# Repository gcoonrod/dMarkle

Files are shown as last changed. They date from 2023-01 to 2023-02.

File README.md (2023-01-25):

<!--
 dMarkle (c) by Greg Coonrod
 
 dMarkle is licensed under a
 Creative Commons Attribution-ShareAlike 4.0 International License.
 
 You should have received a copy of the license along with this
 work. If not, see <http://creativecommons.org/licenses/by-sa/4.0/>.
-->

# dMarkle

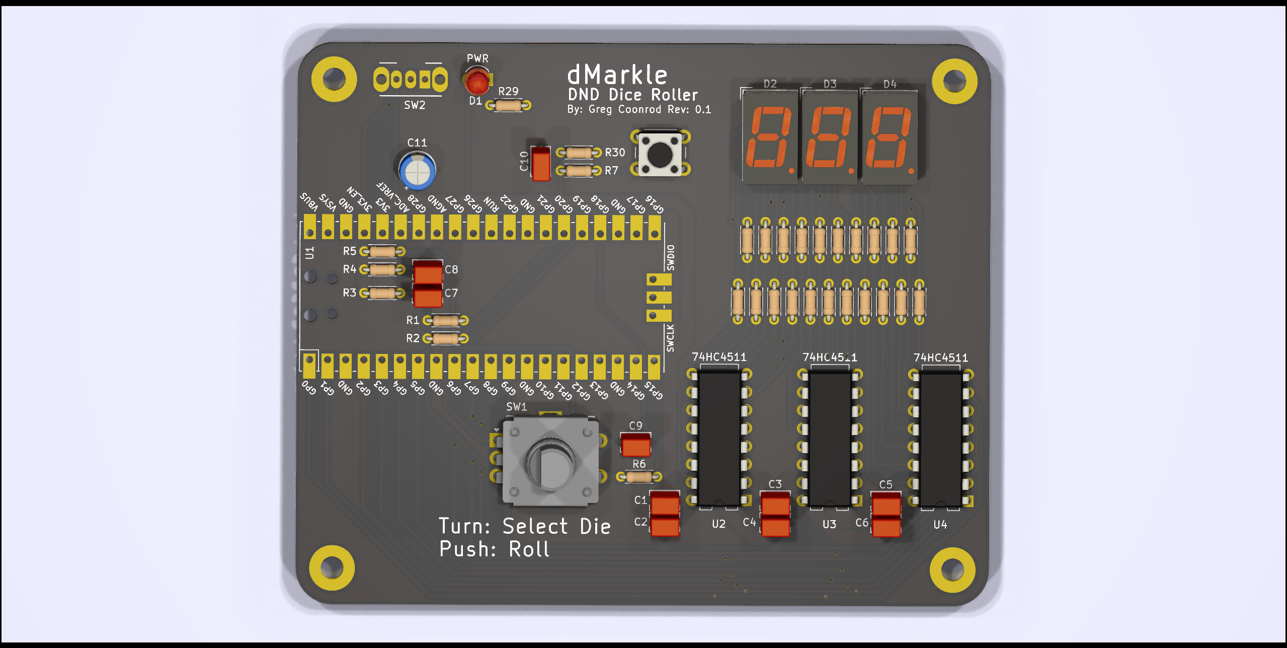
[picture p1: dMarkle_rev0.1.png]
3D View


A Raspberry Pi Pico based dice rolling toy.

## Usage

The dMarkle is programmed to roll one of any d4, d6, d8, d10, d12, d20, or d100 dice. The rotary encoder can be turned to select the die and then pushed to roll.

## Schematic and PCB

- Current [Schematic](./dMarkle-schematic-rev0.1.pdf)
- Current [PCB](./dMarkle-board-rev0.1.pdf)
  - The Pi Pico will be mounted on pin sockets. Hence the components that would otherwise be in an exclusion zone.

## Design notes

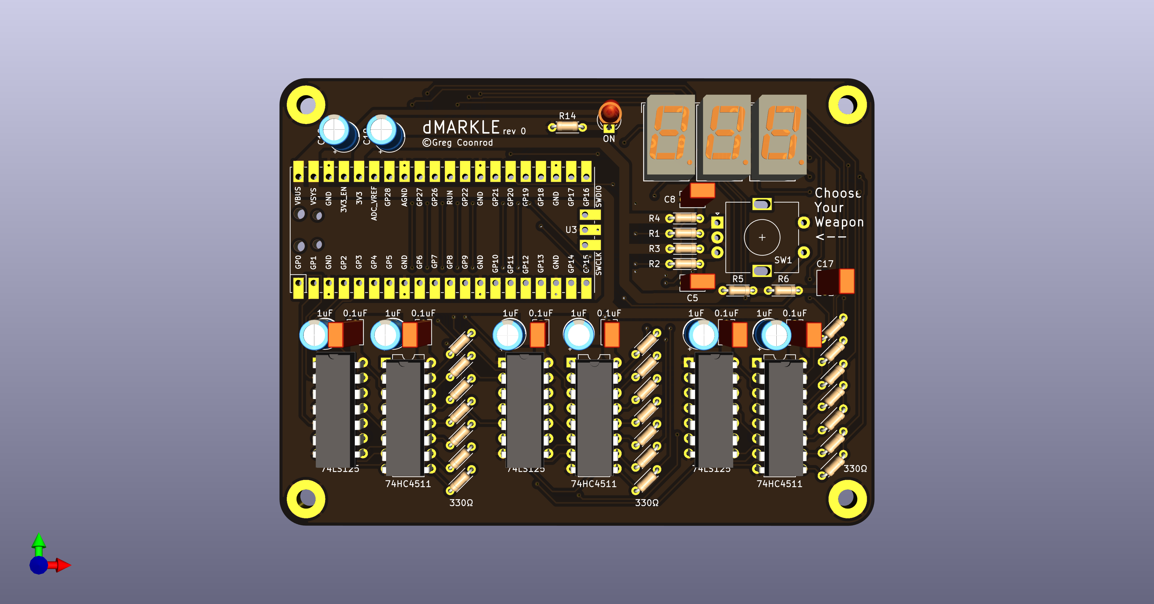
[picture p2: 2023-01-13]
dMarkle_rev0.png

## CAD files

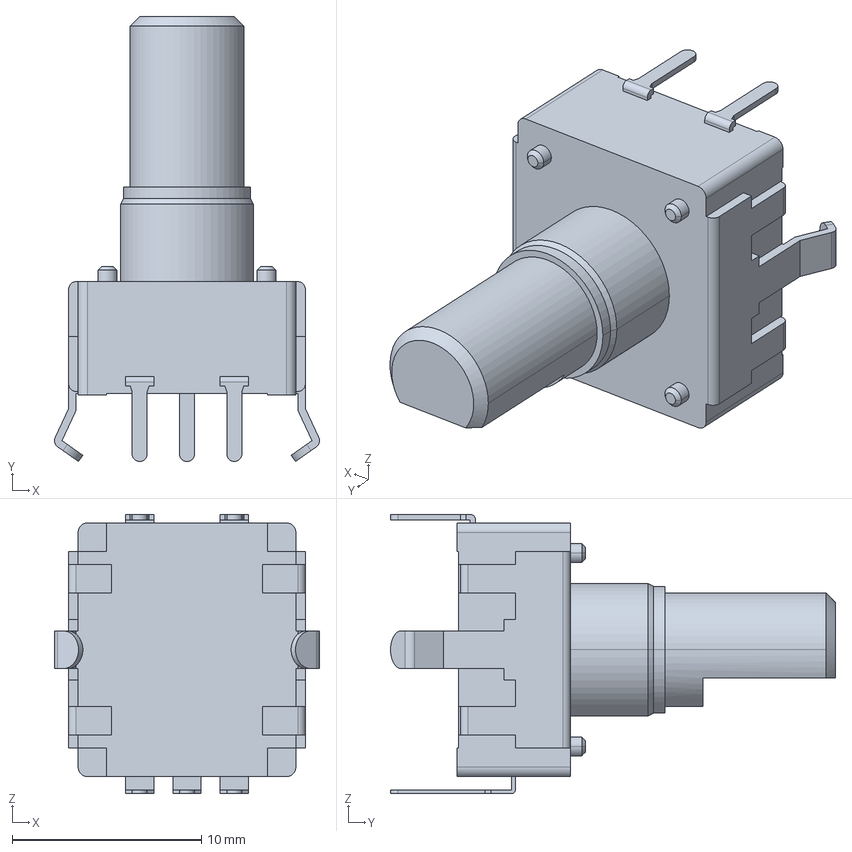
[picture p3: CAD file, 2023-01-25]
models/pec12r-4x20f-sxxxx.stp
14.0 x 23.5 x 14.7 mm

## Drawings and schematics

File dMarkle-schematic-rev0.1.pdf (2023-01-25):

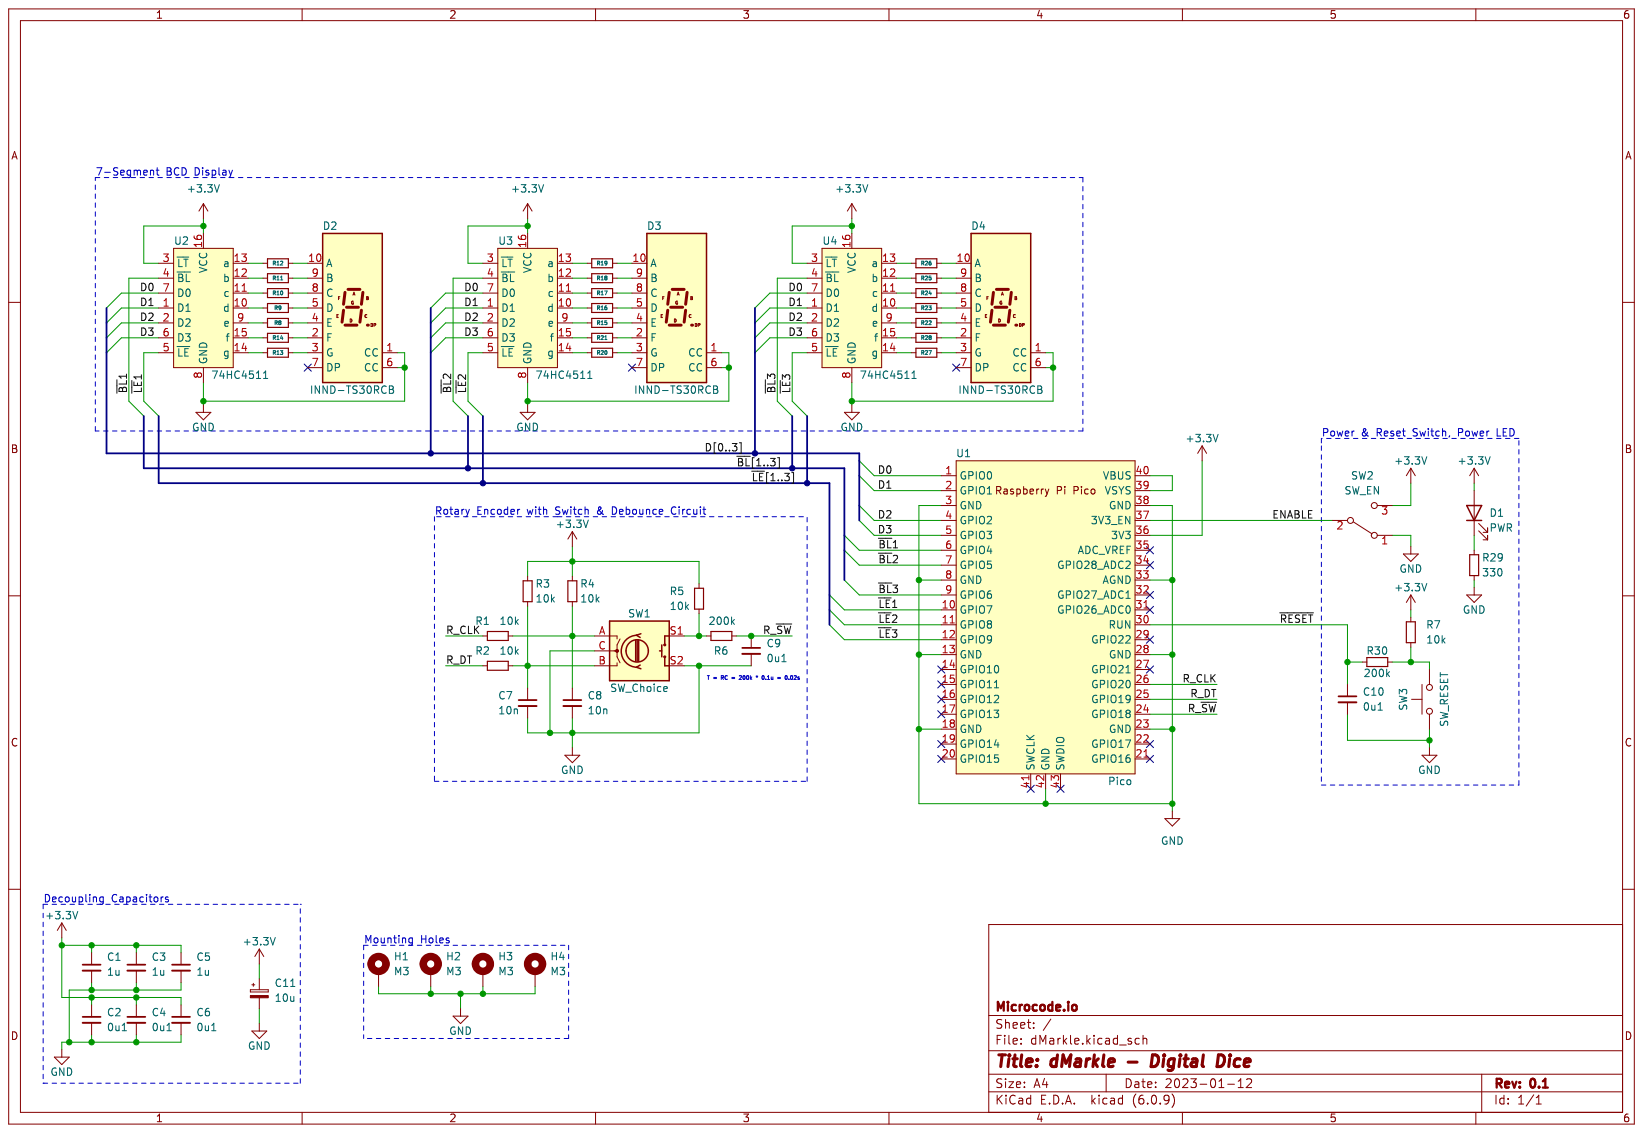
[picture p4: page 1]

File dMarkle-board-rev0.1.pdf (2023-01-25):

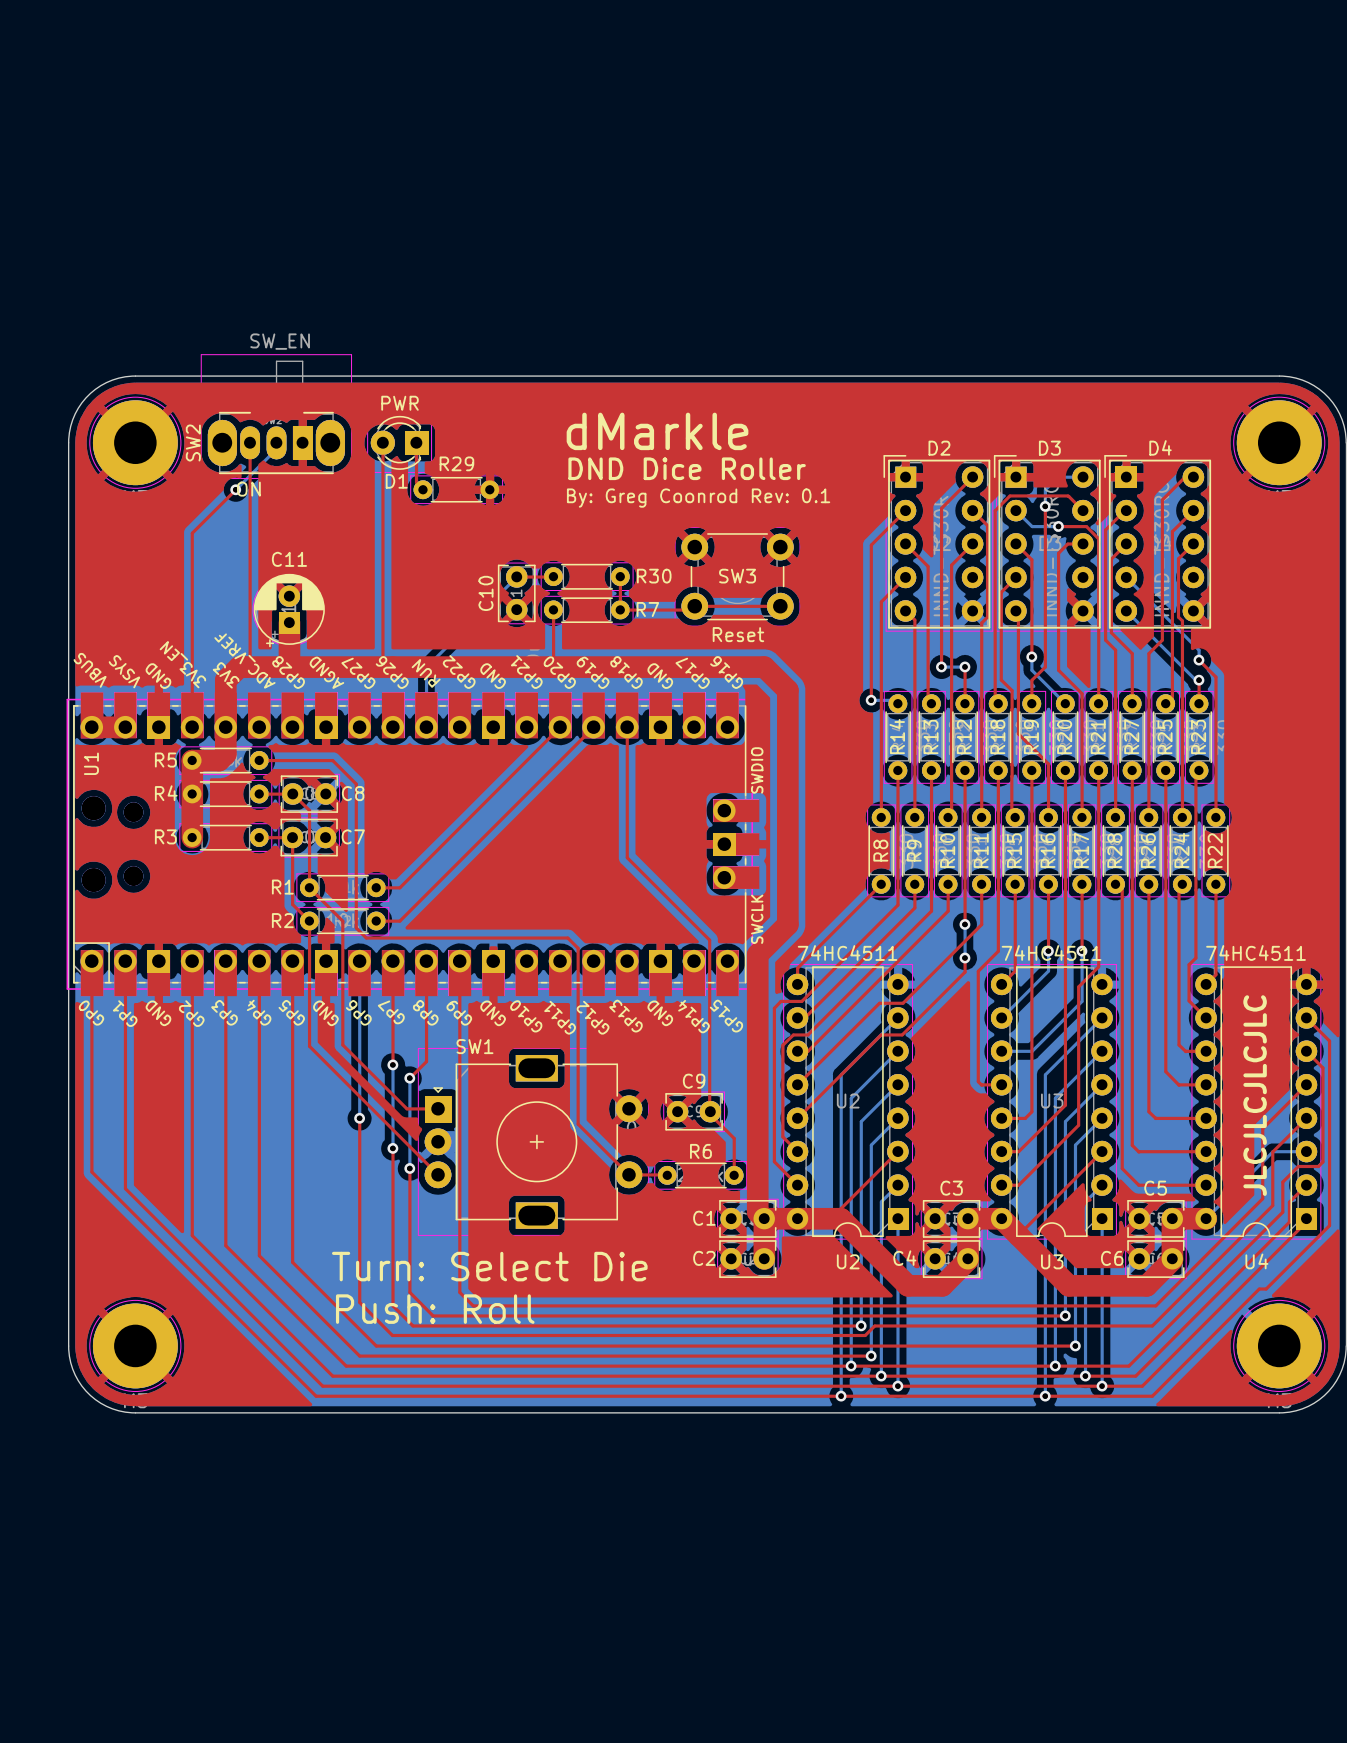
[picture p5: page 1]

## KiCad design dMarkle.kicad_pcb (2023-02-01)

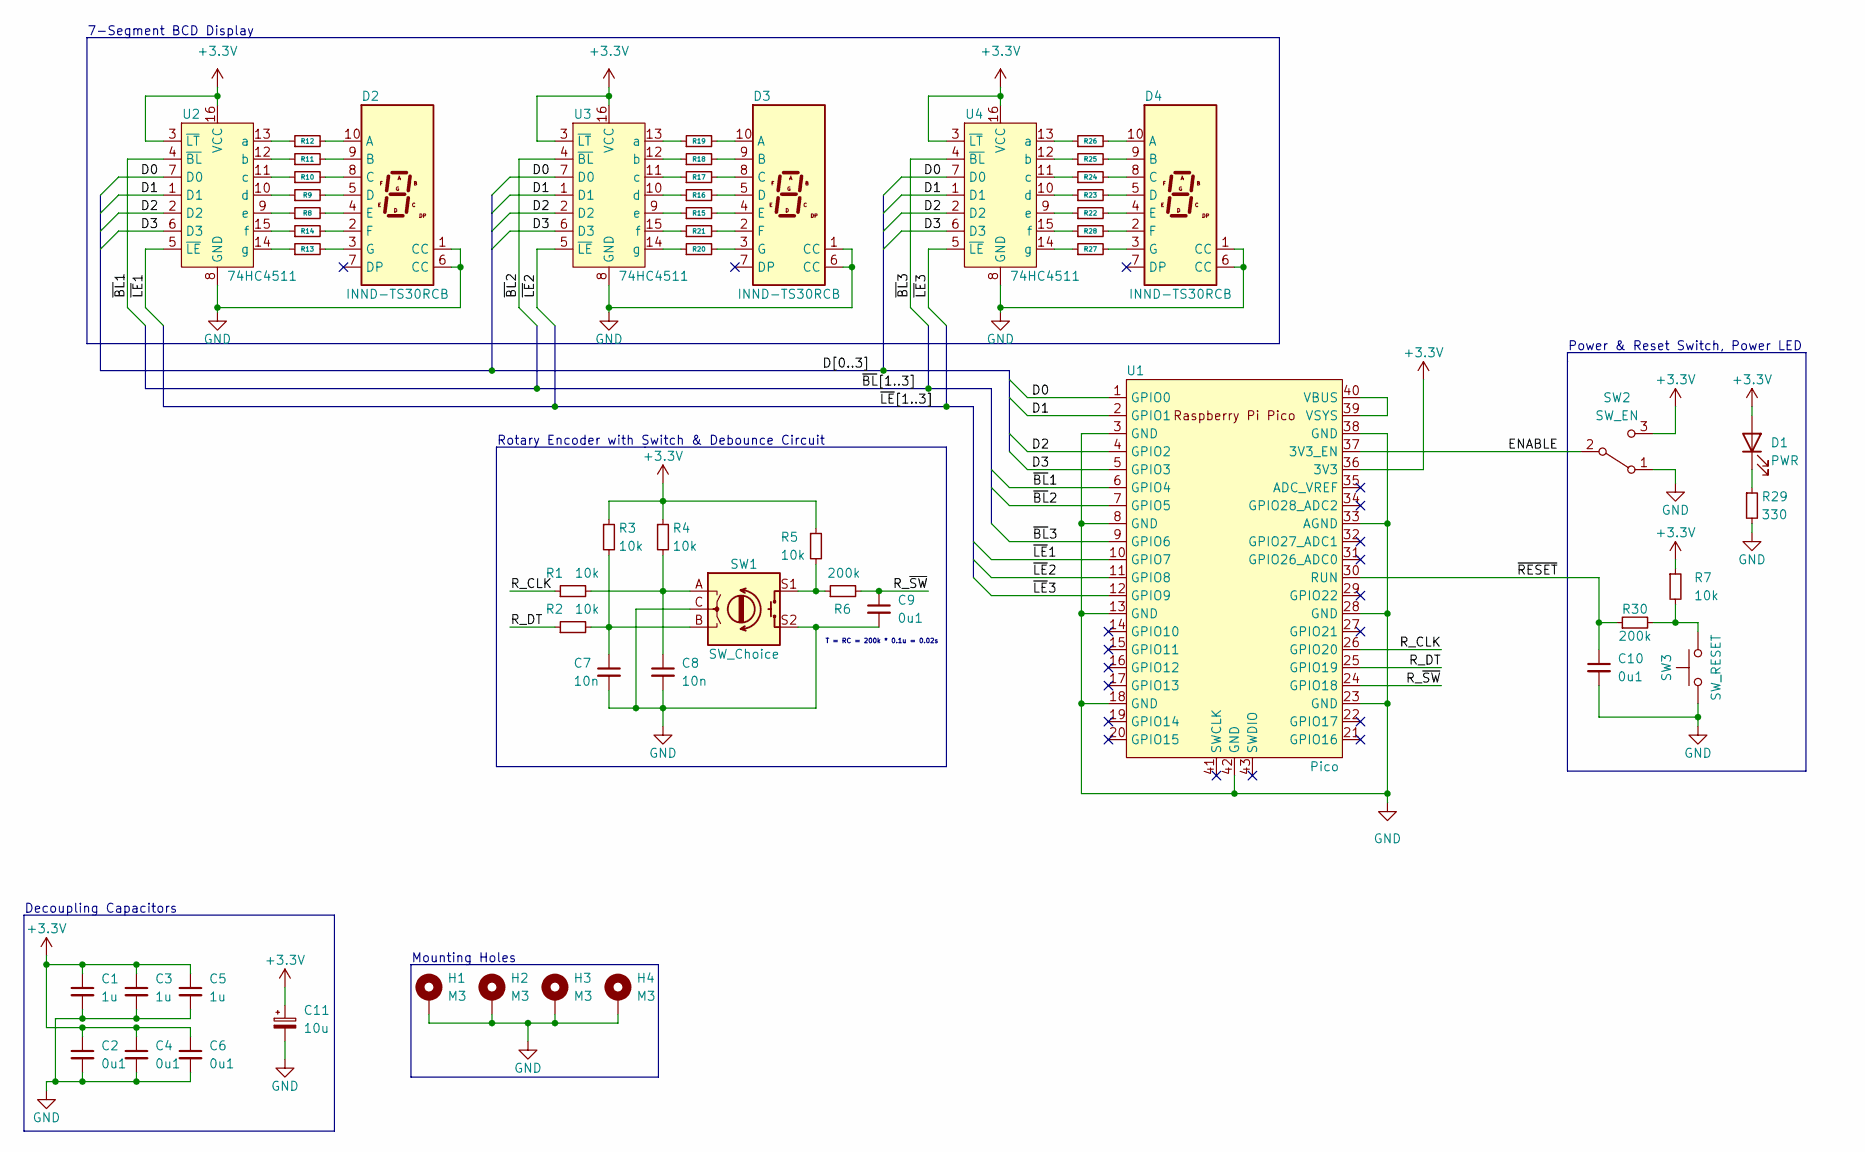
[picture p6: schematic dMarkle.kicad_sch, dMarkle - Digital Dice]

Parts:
C1, C3, C5: 1u; C_Rect_L4.0mm_W2.5mm_P2.50mm; Manufacturer Part Number FG18X5R1H105KRT06
C2, C4, C6, C9, C10: 0u1; C_Rect_L4.0mm_W2.5mm_P2.50mm; Manufacturer Part Number K104K15X7RF5TL2
C7, C8: 10n; C_Rect_L4.0mm_W2.5mm_P2.50mm; Manufacturer Part Number K103K15X7RF5TL2
C11: 10u; CP_Radial_D5.0mm_P2.00mm; Manufacturer Part Number 50YXM10MEFRTA5X11
D1: PWR; LED_D3.0mm; Manufacturer Part Number 151031SS04000
D2, D3, D4: INND-TS30RCB; HDSP-A151; Manufacturer Part Number INND-TS30RCB
H1, H2, H3, H4: M3; MountingHole_3.2mm_M3_Pad
R1, R2, R3, R4, R5, R7: 10k; R_Axial_DIN0204_L3.6mm_D1.6mm_P5.08mm_Horizontal; Manufacturer Part Number MBA02040C1002FRP00
R6, R30: 200k; R_Axial_DIN0204_L3.6mm_D1.6mm_P5.08mm_Horizontal; Manufacturer Part Number MBA02040C2003FCT00
R8, R9, R10, R11, R12, R13, R14, R15, R16, R17, R18, R19, R20, R21, R22, R23, R24, R25, R26, R27, R28, R29: 330; R_Axial_DIN0204_L3.6mm_D1.6mm_P5.08mm_Horizontal; Manufacturer Part Number MBA02040C3300FCT00
SW1: SW_Choice; RotaryEncoder_Alps_EC11E-Switch_Vertical_H20mm; Manufacturer Part Number PEC12R-4220F-S0024
SW2: SW_EN; SW_CuK_OS102011MA1QN1_SPDT_Angled; Manufacturer Part Number OS102011MA1QN1
SW3: SW_RESET; SW_PUSH_6mm; Manufacturer Part Number TL1105F160Q
U1: Pico; RPi_Pico_SMD_TH; Manufacturer Part Number SC0917
U2, U3, U4: 74HC4511; DIP-16_W7.62mm; Manufacturer Part Number CD74HC4511E

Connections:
+3.3V: C1.1, C2.1, C3.1, C4.1, C5.1, C6.1, C11.1, D1.2 (A), R3.1, R4.1, R5.1, R7.1, SW2.3 (C), U1.36 (3V3), U2.3 (~LT), U2.16 (VCC), U3.3 (~LT), U3.16 (VCC), U4.3 (~LT), U4.16 (VCC)
/D0: U1.1 (GPIO0), U2.7 (D0), U3.7 (D0), U4.7 (D0)
/D1: U1.2 (GPIO1), U2.1 (D1), U3.1 (D1), U4.1 (D1)
/D2: U1.4 (GPIO2), U2.2 (D2), U3.2 (D2), U4.2 (D2)
/D3: U1.5 (GPIO3), U2.6 (D3), U3.6 (D3), U4.6 (D3)
/ENABLE: SW2.2 (B), U1.37 (3V3_EN)
/R_CLK: R1.1, U1.26 (GPIO20)
/R_DT: R2.1, U1.25 (GPIO19)
/R_~SW: C9.1, R6.2, U1.24 (GPIO18)
/~BL1: U1.6 (GPIO4), U2.4 (~BL)
/~BL2: U1.7 (GPIO5), U3.4 (~BL)
/~BL3: U1.9 (GPIO6), U4.4 (~BL)
/~LE1: U1.10 (GPIO7), U2.5 (~LE)
/~LE2: U1.11 (GPIO8), U3.5 (~LE)
/~LE3: U1.12 (GPIO9), U4.5 (~LE)
/~RESET: C10.1, R30.1, U1.30 (RUN)
GND: C1.2, C2.2, C3.2, C4.2, C5.2, C6.2, C7.2, C8.2, C9.2, C10.2, C11.2, D2.1 (CC), D2.6 (CC), D3.1 (CC), D3.6 (CC), D4.1 (CC), D4.6 (CC), H1.1, H2.1, H3.1, H4.1, R29.2, SW1.C, SW1.S2, SW2.1 (A), SW3.1, U1.3 (GND), U1.8 (GND), U1.13 (GND), U1.18 (GND), U1.23 (GND), U1.28 (GND), U1.33 (AGND), U1.38 (GND), U1.42 (GND), U2.8 (GND), U3.8 (GND), U4.8 (GND)
unnamed: C7.1, R2.2, R3.2, SW1.B
unnamed: C8.1, R1.2, R4.2, SW1.A
unnamed: D1.1 (K), R29.1
unnamed: D2.2 (F), R14.2
unnamed: D2.3 (G), R13.2
unnamed: D2.4 (E), R8.2
unnamed: D2.5 (D), R9.2
unnamed: D2.8 (C), R10.2
unnamed: D2.9 (B), R11.2
unnamed: D2.10 (A), R12.2
unnamed: D3.2 (F), R21.2
unnamed: D3.3 (G), R20.2
unnamed: D3.4 (E), R15.2
unnamed: D3.5 (D), R16.2
unnamed: D3.8 (C), R17.2
unnamed: D3.9 (B), R18.2
unnamed: D3.10 (A), R19.2
unnamed: D4.2 (F), R28.2
unnamed: D4.3 (G), R27.2
unnamed: D4.4 (E), R22.2
unnamed: D4.5 (D), R23.2
unnamed: D4.8 (C), R24.2
unnamed: D4.9 (B), R25.2
unnamed: D4.10 (A), R26.2
unnamed: R5.2, R6.1, SW1.S1
unnamed: R8.1, U2.9 (e)
unnamed: R9.1, U2.10 (d)
unnamed: R10.1, U2.11 (c)
unnamed: R11.1, U2.12 (b)
unnamed: R12.1, U2.13 (a)
unnamed: R13.1, U2.14 (g)
unnamed: R14.1, U2.15 (f)
unnamed: R15.1, U3.9 (e)
unnamed: R16.1, U3.10 (d)
unnamed: R17.1, U3.11 (c)
unnamed: R18.1, U3.12 (b)
unnamed: R19.1, U3.13 (a)
unnamed: R20.1, U3.14 (g)
unnamed: R21.1, U3.15 (f)
unnamed: R22.1, U4.9 (e)
unnamed: R23.1, U4.10 (d)
unnamed: R24.1, U4.11 (c)
unnamed: R25.1, U4.12 (b)
unnamed: R26.1, U4.13 (a)
unnamed: R27.1, U4.14 (g)
unnamed: R28.1, U4.15 (f)
unnamed: R7.2, R30.2, SW3.2
unnamed: U1.39 (VSYS), U1.40 (VBUS)

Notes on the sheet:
Decoupling Capacitors
Rotary Encoder with Switch & Debounce Circuit
7-Segment BCD Display
T = RC = 200k * 0.1u = 0.02s
Mounting Holes
Power & Reset Switch, Power LED

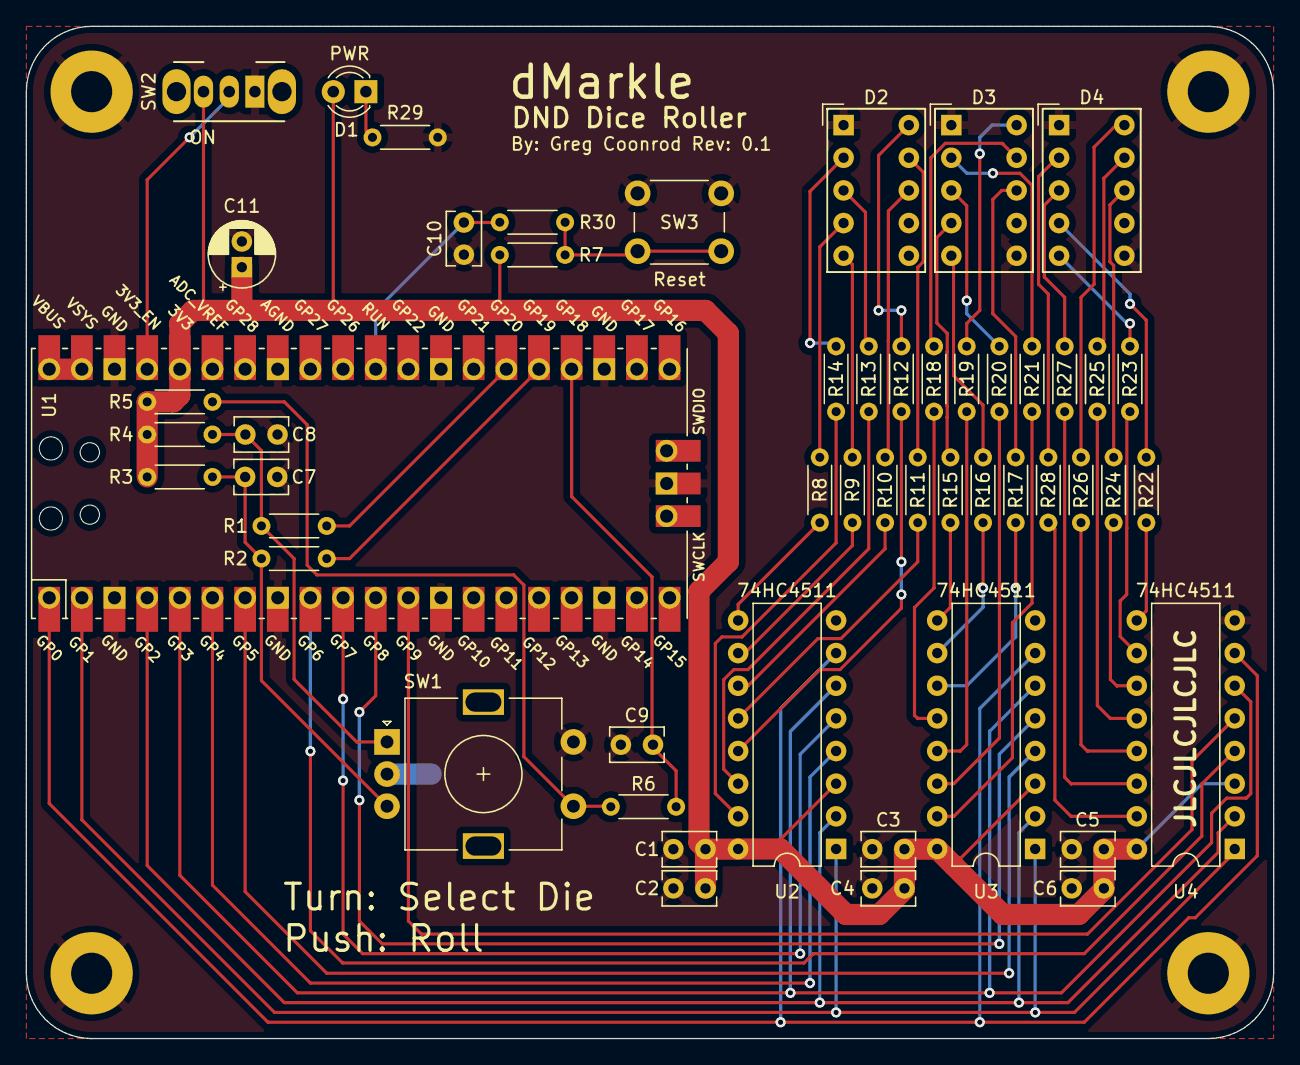
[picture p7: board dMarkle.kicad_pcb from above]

Board: 2 copper layers, 97.0 x 78.7 mm, 56 parts (0 on the bottom side), 65 nets.

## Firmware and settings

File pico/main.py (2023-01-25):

# dMarkle (c) by Greg Coonrod
#
# dMarkle is licensed under a
# Creative Commons Attribution-ShareAlike 4.0 International License.
#
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
from machine import Pin
import time
import random

NUMBERS = {
    0: dict(d3=0, d2=0, d1=0, d0=0, LE=0, BL=1, LT=1),
    1: dict(d3=0, d2=0, d1=0, d0=1, LE=0, BL=1, LT=1),
    2: dict(d3=0, d2=0, d1=1, d0=0, LE=0, BL=1, LT=1),
    3: dict(d3=0, d2=0, d1=1, d0=1, LE=0, BL=1, LT=1),
    4: dict(d3=0, d2=1, d1=0, d0=0, LE=0, BL=1, LT=1),
    5: dict(d3=0, d2=1, d1=0, d0=1, LE=0, BL=1, LT=1),
    6: dict(d3=0, d2=1, d1=1, d0=0, LE=0, BL=1, LT=1),
    7: dict(d3=0, d2=1, d1=1, d0=1, LE=0, BL=1, LT=1),
    8: dict(d3=1, d2=0, d1=0, d0=0, LE=0, BL=1, LT=1),
    9: dict(d3=1, d2=0, d1=0, d0=1, LE=0, BL=1, LT=1),
}

DICE = {
    'd4': dict(value=4, bits=3),
    'd6': dict(value=6, bits=3),
    'd8': dict(value=8, bits=4),
    'd10': dict(value=10, bits=4),
    'd12': dict(value=12, bits=4),
    'd20': dict(value=20, bits=5),
    'd100': dict(value=100, bits=7)
}

DICE_LIST = ['d4', 'd6', 'd8', 'd10', 'd12', 'd20', 'd100']


class Direction:
    LEFT = 0
    RIGHT = 1


class Digit:

    def __init__(self, pins):
        self.d3 = Pin(pins['d3'], Pin.OUT, value=0)
        self.d2 = Pin(pins['d2'], Pin.OUT, value=0)
        self.d1 = Pin(pins['d1'], Pin.OUT, value=0)
        self.d0 = Pin(pins['d0'], Pin.OUT, value=0)
        self.blank = Pin(pins['BL'], Pin.OUT, value=0)
        self.latch = Pin(pins['LE'], Pin.OUT, value=1)

    def set_value(self, value, blank=False):
        if blank:
            self.blank.off()
        else:
            self.blank.on()
            lookup = NUMBERS[value]
            self.d0.value(lookup['d0'])
            self.d1.value(lookup['d1'])
            self.d2.value(lookup['d2'])
            self.d3.value(lookup['d3'])
            time.sleep_us(50)
            self.latch.off()
            time.sleep_us(50)
            self.latch.on()
            time.sleep_us(50)

    def set_blank(self, value=True):
        if value:
            self.blank.off()
        else:
            self.blank.on()


class Display:

    def __init__(self):
        self.ones_digit = Digit(dict(d3=3, d2=2, d1=1, d0=0, LE=9, BL=6))
        self.tens_digit = Digit(dict(d3=3, d2=2, d1=1, d0=0, LE=8, BL=5))
        self.hundreds_digit = Digit(dict(d3=3, d2=2, d1=1, d0=0, LE=7, BL=4))

    def display_number(self, value):
        if value > 999 or value < 0:
            self.show_error()
        else:
            digits = list(str(value))
            digits.reverse()
            num_digits = len(digits)
            if num_digits > 0:
                self.ones_digit.set_value(int(digits[0]))
            else:
                self.ones_digit.set_blank()

            if num_digits > 1:
                self.tens_digit.set_value(int(digits[1]))
            else:
                self.tens_digit.set_blank()

            if num_digits > 2:
                self.hundreds_digit.set_value(int(digits[2]))
            else:
                self.hundreds_digit.set_blank()

    def show_error(self):
        print('Oops')


class RotaryEncoder:

    def __init__(self, clk_pin, dt_pin, btn_pin):
        self.clk = Pin(clk_pin, Pin.IN)
        self.dt = Pin(dt_pin, Pin.IN)

        # Active Low Button
        self.btn = Pin(btn_pin, Pin.IN)

        self.press_handler = None
        self.turn_handler = None

        self.clk.irq(self.__clk_irq_handler, Pin.IRQ_FALLING)
        self.btn.irq(self.__btn_irq_handler, Pin.IRQ_FALLING)

    def register_press_handler(self, handler_func):
        self.press_handler = handler_func

    def register_turn_handler(self, handler_func):
        self.turn_handler = handler_func

    def __clk_irq_handler(self, pin):
        dt_value = self.dt.value()
        #print('IRQ: dt={}'.format(dt_value))
        if dt_value == 0:
            if self.turn_handler != None:
                self.turn_handler(Direction.LEFT)
        else:
            if self.turn_handler != None:
                self.turn_handler(Direction.RIGHT)

    def __btn_irq_handler(self, pin):
        if self.press_handler != None:
            self.press_handler()


class Program:

    def __init__(self):
        self.display = Display()
        self.encoder = RotaryEncoder(clk_pin=20, dt_pin=19, btn_pin=18)
        self.encoder.register_press_handler(self.handle_press)
        self.encoder.register_turn_handler(self.handle_turn)
        self.current_die_idx = 0
        self.current_die = DICE[DICE_LIST[self.current_die_idx]]
        self.display.display_number(self.current_die['value'])

    def roll_dice(self):
        max_value = self.current_die['value']
        bits = self.current_die['bits']

        result = random.getrandbits(bits)
        while result == 0 or result > max_value:
            result = random.getrandbits(bits)

        return result

    def handle_turn(self, direction: Direction):
        if direction == Direction.LEFT:
            if self.current_die_idx == 0:
                self.current_die_idx = 6
            else:
                self.current_die_idx -= 1
        elif direction == Direction.RIGHT:
            if self.current_die_idx == 6:
                self.current_die_idx = 0
            else:
                self.current_die_idx += 1
        else:
            print('WTF')

        self.current_die = DICE[DICE_LIST[self.current_die_idx]]
        num_to_display = self.current_die['value']
        self.display.display_number(num_to_display)
        print('Current Die: {}'.format(self.current_die['value']))

    def handle_press(self):
        roll = self.roll_dice()
        print('{} rolled a {}'.format(DICE_LIST[self.current_die_idx], roll))
        self.display.display_number(roll)


# Main
random.seed(None)
program = Program()

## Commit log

2023-01-13 Rev 0 complete
    [dMarkle.kicad_pcb, dMarkle.kicad_sch]
2023-01-18 add placeholder for pico code
2023-01-18 Add another LS125 for rotary encoder output.
    [dMarkle.kicad_sch]
2023-01-19 Begin splitting design into top and bottom boards.
    [dMarkle.kicad_sch, dMarkle_Bottom.kicad_pcb, dMarkle_Bottom.kicad_sch]
2023-01-19 Update library pathing.
    [dMarkle_Bottom.kicad_sch]
2023-01-23 Initial split of dMarkle board
    [dMarkle_Bottom.kicad_pcb, dMarkle_Bottom.kicad_sch, dMarkle_Top.kicad_pcb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]
2023-01-23 WIP pico software
2023-01-24 Rev 0.1
    [dMarkle.kicad_pcb, dMarkle.kicad_sch]
2023-01-25 Fixed GPIO pin numbering. Counter working.
    [main.py]
2023-01-25 All 5V usage removed. Rev0.1 complete.
    [dMarkle.kicad_pcb, dMarkle.kicad_sch, pec12r-4x20f-sxxxx.stp]
2023-01-25 Remove board split as not needed.
    [dMarkle_Bottom.kicad_pcb, dMarkle_Bottom.kicad_sch, dMarkle_Top.kicad_pcb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]
2023-01-25 Clean up schematic and generate output for rev 0.1
    [dMarkle.kicad_sch]
2023-01-25 Readme updates and minor silkscreen changes.
    [dMarkle.kicad_pcb]
2023-02-01 Board and parts ordered.
    [dMarkle.kicad_pcb, dMarkle.kicad_sch]
